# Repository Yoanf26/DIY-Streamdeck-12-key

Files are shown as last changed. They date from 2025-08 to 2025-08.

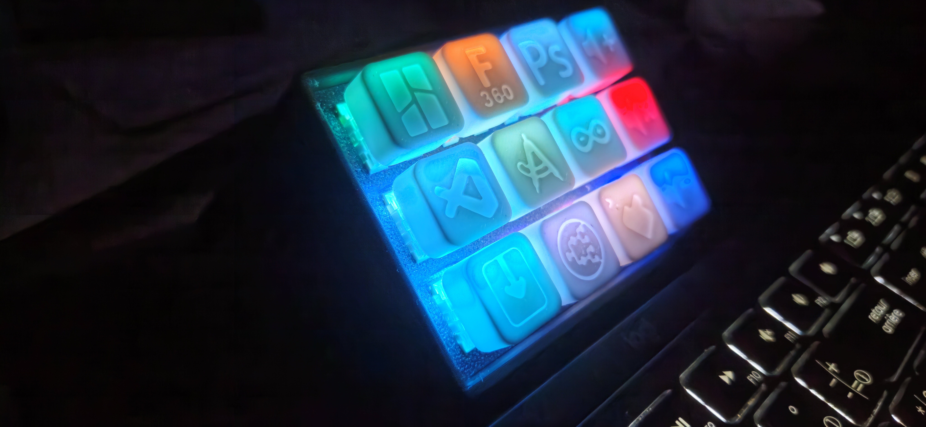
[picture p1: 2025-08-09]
20250809_225233.jpg

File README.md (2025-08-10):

I created a streamdeck with 12 keys to make it easier for me to use my PC. For my part, I have 9 keys for opening applications and 3 keys for volume control. But it is customizable as desired. I even allowed myself to add LEDs corresponding to the main color of each application.

Equipment list:

 - Arduino Pro Micro
 - Cherry MX Blue (or other) x12
 - WS2812B LED x12
 - 3D Printer
 - Filament in the color of your choice (Personally, I chose black (Bambu) for the shell, blue nebula (Bambu) for the keycaps, and white (Bambu) for the keys that I customized)
 - 3D modeling software (For me it's Fusion 360)
 - Wiring wire
 - Soldering iron...
 - Arduino IDE 2.3.6 software with the Keyboard and FastLED Library installed and Arduino AVR Boards on Board Manager
 
Tutorial:

1. Print the Main_body, plate_switches and Stream Deck Leds Adapter files (0.2mm layer, 20% infill).
2. Install the 12 Cherry MX Blue (or other) on the plate_switches.
3. Solder the wiring to the keys according to the diagram in the DIY Streamdeck 12 key Wiring.pdf file.
4. Prepare the 12 WS2812B LEDs using the Stream Deck LED Adapter in 3x4 LED strips according to the diagram in the DIY Streamdeck 12 key Wiring.pdf file.
5. Install the WS2812B strips on the plate_switches according to the following plan:

```
       Key1     Key2     Key3     Key4
    -  Led0  -  Led1  -  Led2  -  Led3  -
       Key5     Key6     Key7     Key8  |
    -  Led7  -  Led6  -  Led5  -  Led4  -
    |  Key9     Key10    Key11    Key12
    -  Led8  -  Led9  -  Led10 -  Led11
```

7. Solder all the wiring to the Arduino Pro Micro according to the diagram in the DIY Streamdeck 12 key Wiring.pdf file.
8. Install everything on the Main_body.
9. Optional: Create your keycaps using the Cherry MX Keycap Empty file as a reference.
10. Print 12 Cherry MX Keycap Emptys or your custom keycaps, or even, if you're interested, use keys already created in the Cherry MX Keycap Custom file.
11. Install the keycaps on Cherry MX (or other) devices.
12. Connect the Arduino Pro Micro to your PC via USB. A USB3 port on the PC is recommended
13. If the Arduino IDE is not installed, install it. Otherwise, proceed to the next step.
14. Open the Stream_Deck_12_buttons.ino file (check that you have the Library and Board installed).
15. Select your Arduino Leonardo board with the correct COM port.
16. If you want to change the color of an LED, this is located at the beginning of the "void setup" section with the RGB codes. Do not exceed the setBrightness parameter to 60, otherwise there is a risk of over-consumption of too much power on the USB port.
17. Upload and enjoy.

The code provides the keys F13 to F24. You can use them in your software that supports these keys, or you can use a Key Remapper. Personally, I use the PowerToys keymap, which I remap the volume keys directly into. Otherwise, I remap them to the CTRL + SHIFT + ALT + (Letter) key combination.
So, to launch an application, I go to the application's properties to enter this same key combination. For example, for Bambu Studio, I use the CTRL + SHIFT + ALT + B key combination. And I remapped the F13 key to CTRL + SHIFT + ALT + B.

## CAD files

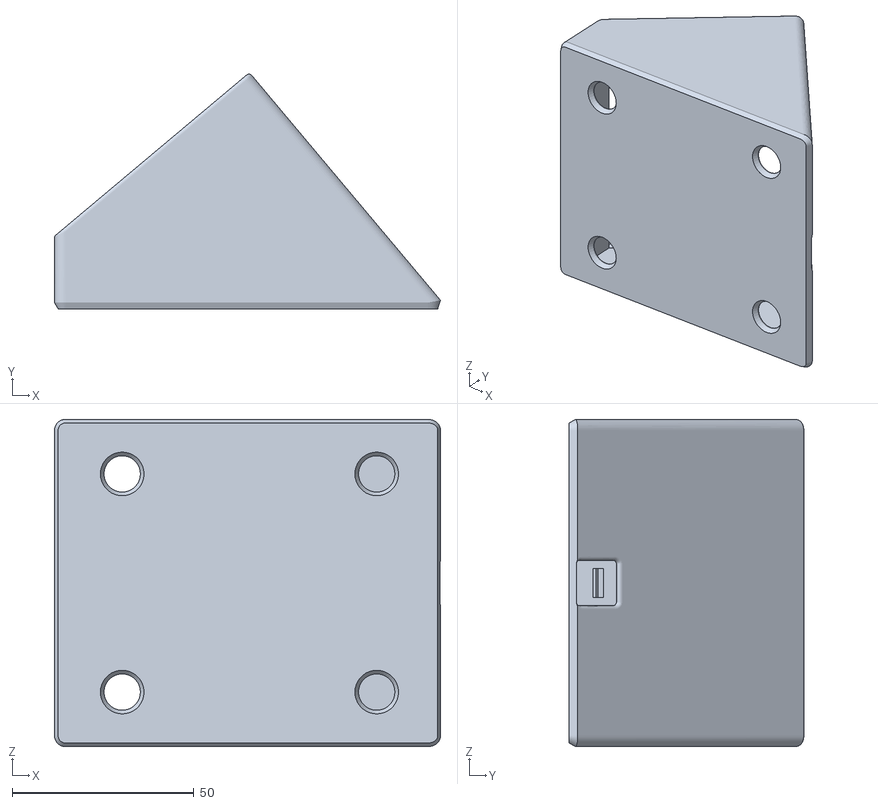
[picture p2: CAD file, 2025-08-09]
Main_body.STL
106.2 x 64.6 x 90.0

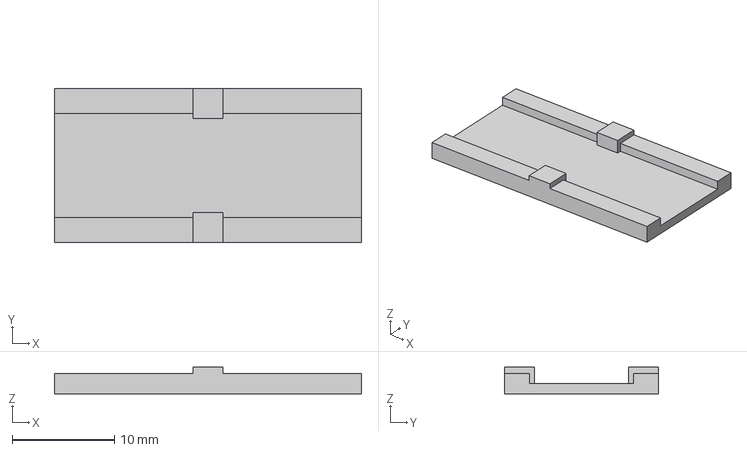
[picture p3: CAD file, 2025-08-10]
Adaptateur Leds Stream Deck.3mf
30.0 x 15.0 x 2.60 mm

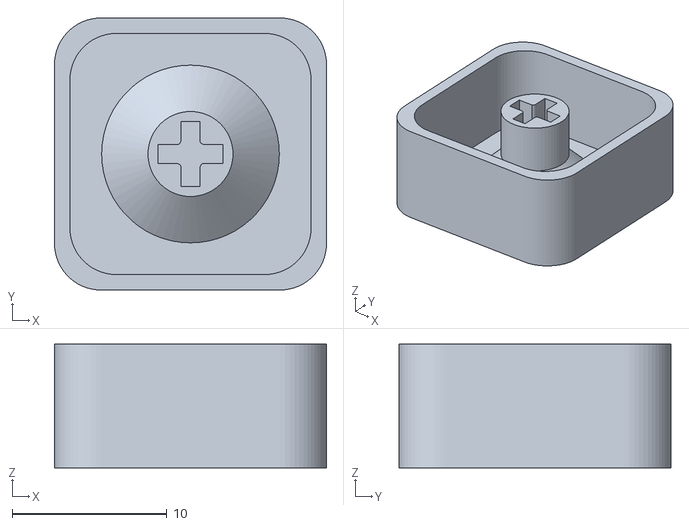
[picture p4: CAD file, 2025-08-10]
Cherry MX Keycap empty.stl
17.6 x 17.6 x 8.00

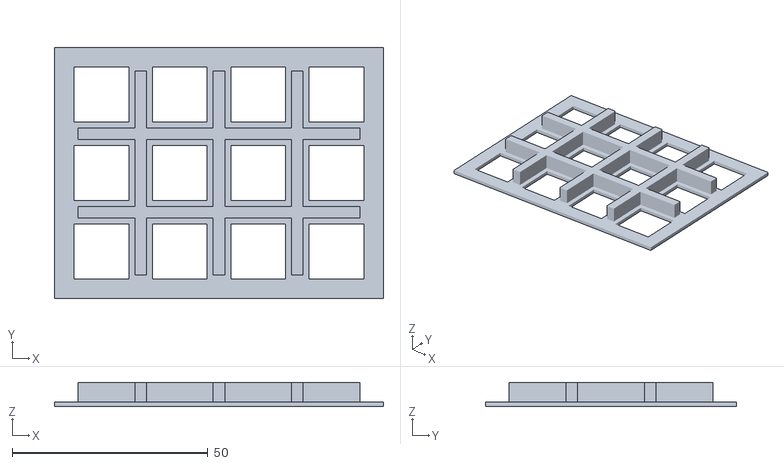
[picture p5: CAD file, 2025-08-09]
plate_switches.STL
84.0 x 64.0 x 6.20

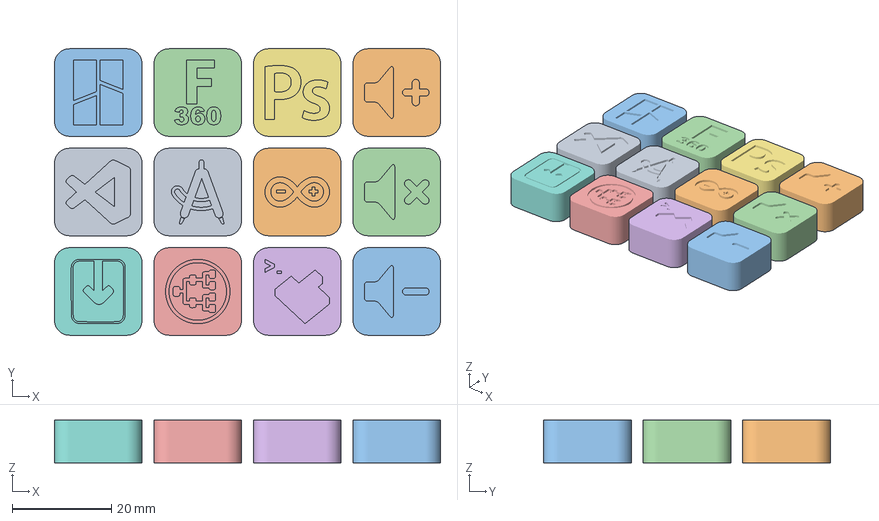
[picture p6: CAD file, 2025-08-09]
Cherry MX Keycap Custom.3mf
77.6 x 57.6 x 8.60 mm
Cherry MX Keycap Android
Cherry MX Keycap Arduino
Cherry MX Keycap Bambu
Cherry MX Keycap Fusion
Cherry MX Keycap MQTT
Cherry MX Keycap MobaXterm
Cherry MX Keycap Photoshop
Cherry MX Keycap Uniget
Cherry MX Keycap VSCode
Cherry MX Keycap Vol +
Cherry MX Keycap Vol -
Cherry MX Keycap VolX

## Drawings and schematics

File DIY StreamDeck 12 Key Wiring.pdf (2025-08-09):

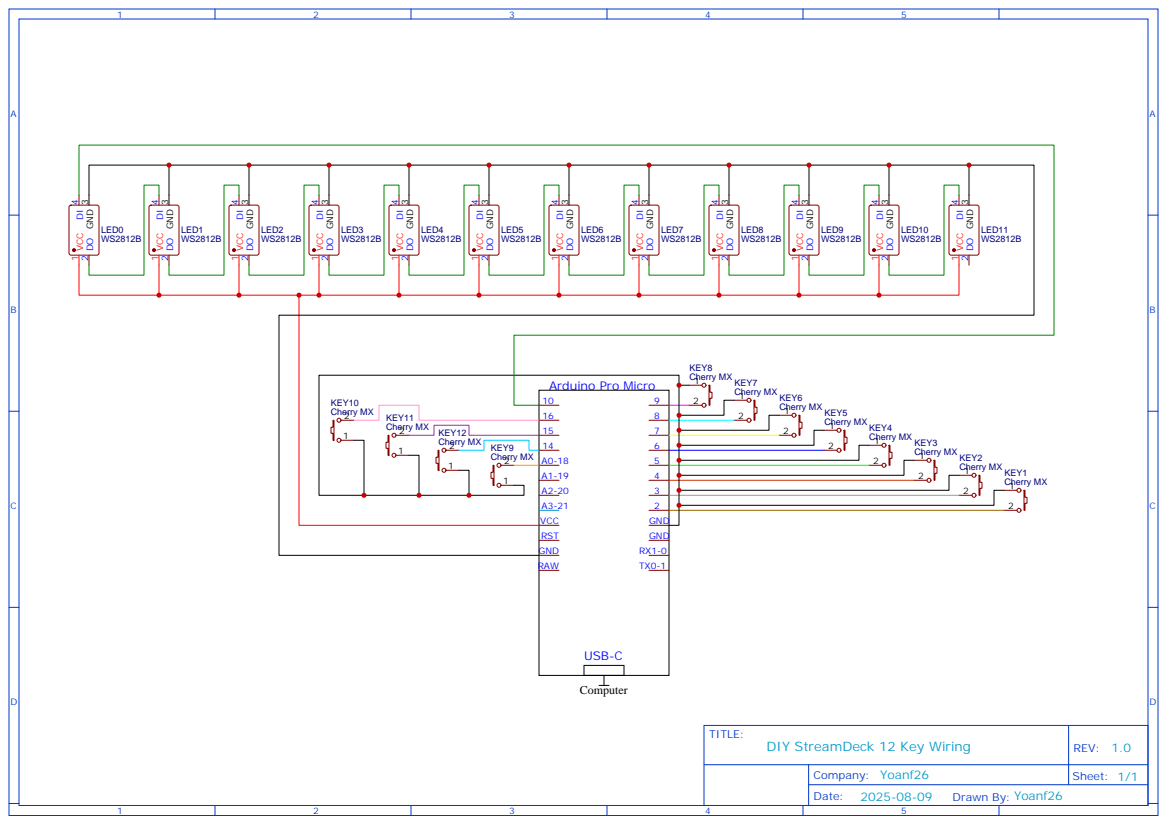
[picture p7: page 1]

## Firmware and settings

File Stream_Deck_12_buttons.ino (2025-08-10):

// Key definitions
#define BUTTON_KEY1 KEY_F13
#define BUTTON_KEY2 KEY_F14
#define BUTTON_KEY3 KEY_F15
#define BUTTON_KEY4 KEY_F16
#define BUTTON_KEY5 KEY_F17
#define BUTTON_KEY6 KEY_F18
#define BUTTON_KEY7 KEY_F19
#define BUTTON_KEY8 KEY_F20
#define BUTTON_KEY9 KEY_F21
#define BUTTON_KEY10 KEY_F22
#define BUTTON_KEY11 KEY_F23
#define BUTTON_KEY12 KEY_F24
 
// Pin definitions
#define BUTTON_PIN1 2
#define BUTTON_PIN2 3
#define BUTTON_PIN3 4
#define BUTTON_PIN4 5
#define BUTTON_PIN5 6
#define BUTTON_PIN6 7
#define BUTTON_PIN7 8
#define BUTTON_PIN8 9
#define BUTTON_PIN9 18
#define BUTTON_PIN10 16
#define BUTTON_PIN11 14
#define BUTTON_PIN12 15
 
// Include Library
#include "Keyboard.h"
#include <FastLED.h>

// WS2812b strip settings
#define DATA_PIN 10
#define NUM_LEDS 12

// Define the array of leds
CRGB leds[NUM_LEDS];

// Button helper class for handling press/release and debouncing
class button {
  public:
  const char key;
  const uint8_t pin;
 
  button(uint8_t k, uint8_t p) : key(k), pin(p){}
 
  void press(boolean state){
    if(state == pressed || (millis() - lastPressed  <= debounceTime)){
      return; // Nothing to see here, folks
    }
 
    lastPressed = millis();
 
    state ? Keyboard.press(key) : Keyboard.release(key);    
    pressed = state;
  }
 
  void update(){
    press(!digitalRead(pin));
  }
 
  private:
  const long debounceTime = 30;
  unsigned long lastPressed;
  boolean pressed = 0;
} ;
 
// Button objects, organized in array
button buttons[] = {
  {BUTTON_KEY1, BUTTON_PIN1},
  {BUTTON_KEY2, BUTTON_PIN2},
  {BUTTON_KEY3, BUTTON_PIN3},
  {BUTTON_KEY4, BUTTON_PIN4},
  {BUTTON_KEY5, BUTTON_PIN5},
  {BUTTON_KEY6, BUTTON_PIN6},
  {BUTTON_KEY7, BUTTON_PIN7},
  {BUTTON_KEY8, BUTTON_PIN8},
  {BUTTON_KEY9, BUTTON_PIN9},
  {BUTTON_KEY10, BUTTON_PIN10},
  {BUTTON_KEY11, BUTTON_PIN11},
  {BUTTON_KEY12, BUTTON_PIN12},
};
 
const uint8_t NumButtons = sizeof(buttons) / sizeof(button);
const uint8_t ledPin = 17;

  // KEY - LED path
  //     Key1     Key2     Key3     Key4
  //  -  Led0  -  Led1  -  Led2  -  Led3  -
  //     Key5     Key6     Key7     Key8  |
  //  -  Led7  -  Led6  -  Led5  -  Led4  -
  //  |  Key9     Key10    Key11    Key12
  //  -  Led8  -  Led9  -  Led10 -  Led11

void setup() { 
  // Set WS22812b LED configuration for application color based on keystrokes
  FastLED.addLeds<WS2812B, DATA_PIN, GRB>(leds, NUM_LEDS);
  FastLED.setBrightness(40);
  leds[0].setRGB( 0, 174, 66); //Bambu Studio
  leds[1].setRGB( 247, 112, 1); //Fusion 360
  leds[2].setRGB( 49, 168, 255); //Photoshop
  leds[3].setRGB( 0, 153, 203); //Volume Up
  leds[4].setRGB( 255, 0, 0); //Volume Mute
  leds[5].setRGB( 0, 151, 157); //Arduino IDE
  leds[6].setRGB( 52, 168, 83); //Android Studio
  leds[7].setRGB( 33, 165, 242); //VS Code
  leds[8].setRGB( 15, 212, 246); //Uniget UI
  leds[9].setRGB( 76, 111, 146); //MQTT Explorer
  leds[10].setRGB( 181, 169, 116); //MobaXterm
  leds[11].setRGB( 0, 57, 203); //Volume Minus
  FastLED.show();

  // Safety check. Ground pin #1 (RX) to cancel keyboard inputs.
  pinMode(1, INPUT_PULLUP);
  if(!digitalRead(1)){
    failsafe();
  }
 
  // Set LEDs Off. Active low.
  pinMode(ledPin, OUTPUT);
  digitalWrite(ledPin, HIGH);
  TXLED0;
 
  for(int i = 0; i < NumButtons; i++){
    pinMode(buttons[i].pin, INPUT_PULLUP);
  }

}

void loop() {
  for(int i = 0; i < NumButtons; i++){
    buttons[i].update();
  }
}
 
void failsafe(){
  for(;;){} // Just going to hang out here for awhile :D
}
